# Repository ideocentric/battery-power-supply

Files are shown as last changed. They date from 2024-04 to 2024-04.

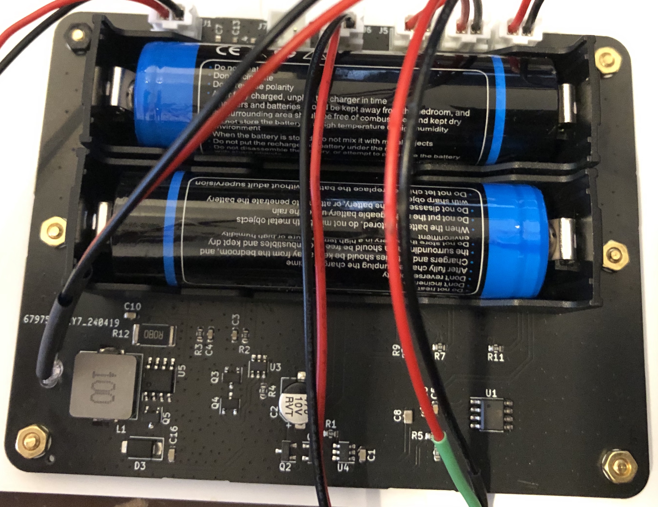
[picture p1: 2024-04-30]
battery-charger-supply.jpg

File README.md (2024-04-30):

# battery-power-supply
The purpose of this project is to have a rechargeable battery intended to be inside an enclosure for various synthesizer designs, however, it can be utilized for any purpose.

The motivation for this project was that I have not found an adequate solution.  There are a number of current solutions available, but the following limitations create issues for the overall design.

1.  Soldered on USB charging ports
2.  Soldered on power switch
3.  Soldered on power, charging and charge LEDs

Due to the above, they do not suite the usage inside of a project enclosure without desoldering these components and attaching wires in their place for panel mount switches, power and LEDs.

I have, however, found one solution that satisfied the above issues.  Unfortunately, these devices produced audible frequencies that prevented it being functional as a power supply for a sythesizer.

Due to the above conditions, I reached out to work with an engineer to help create the schematic and PCB layout for this purpose.  

The devise is intended to be used with 2 18650 batteries.  The JST connectors are provided to hook up the components such as the DC Barrel Jack for charging, 5v output for the device, Power switch and LEDs for Power, Charging and Charged status indicators.

The power supply should be 5v2a (or 5v3a).  Output is 5v1a.

I had the device manufactured at https://jlcpcb.com of which all components are normal stock items.

# Known Issues:
The current solution does not provide protection for low or short battery (perhaps this will be modified in a future version).

The status light output of the CN3302 IC is a little vague in it’s output as both lights appear to be on during charging.

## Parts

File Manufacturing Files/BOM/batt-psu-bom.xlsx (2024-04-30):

Comment | MFR | MFR-PN | Designator | Footprint | JLCPCB Part #（optional）
BH-18650-A5BJ001-2D | MYOUNG | BH-18650-A5BJ001-2D | BT1, BT2 | Battery:BatteryHolder_MPD_BH-18650-PC2 | C19184083
CL10A106MA8NRNC | Samsung Electro-Mechanics | CL10A106MA8NRNC | C1, C7, C10, C16 | Capacitor_SMD:C_0603_1608Metric | C96446
RVT1A471M0607 | Honor Elec | RVT1A471M0607 | C2 | Capacitor_SMD:CP_Elec_6.3x7.7 | C87858
0603B104K250CT | Walsin Tech Corp | 0603B104K250CT | C3, C4, C5, C13 | Capacitor_SMD:C_0603_1608Metric | C83054
0603X105M250NT | FH (Guangdong Fenghua Advanced Tech) | 0603X105M250NT | C6, C14 | Capacitor_SMD:C_0603_1608Metric | C2857985
CL21A226MAYNNNE | Samsung Electro-Mechanics | CL21A226MAYNNNE | C8 | Capacitor_SMD:C_0603_1608Metric | C602037
SS34 | JUXING | SS34 | D3 | Diode_SMD:D_SMA | C3011102
B2B-XH-A(LF)(SN) | JST | B2B-XH-A(LF)(SN) | J1, J2, J3, J5, J6, J7 | Connector_JST:JST_XH_B2B-XH-A_1x02_P2.50mm_Vertical | C158012
SLO1040H100MTT | Sunltech Tech | SLO1040H100MTT | L1 | Inductor_SMD:L_Wuerth_HCI-1040 | C182194
SI2347DS-T1-GE3 | Vishay Intertech | SI2347DS-T1-GE3 | Q1, Q2 | Package_TO_SOT_SMD:SOT-23 | C145002
FS3402 | FOSAN | FS3402 | Q3, Q4, Q5 | Package_TO_SOT_SMD:SOT-23 | C2926128
FRC0603J474 TS | FOJAN | FRC0603J474 TS | R1 | Resistor_SMD:R_0603_1608Metric | C2907171
FRC0603J331 TS | FOJAN | FRC0603J331 TS | R2, R3, R7, R9, R11 | Resistor_SMD:R_0603_1608Metric | C2907152
FRC0603J202 TS | FOJAN | FRC0603J202 TS | R4 | Resistor_SMD:R_0603_1608Metric | C2907137
FRC0603F6201TS | FOJAN | FRC0603F6201TS | R5 | Resistor_SMD:R_0603_1608Metric | C2907054
FRC0603J202 TS | FOJAN | FRC0603J202 TS | R6 | Resistor_SMD:R_0603_1608Metric | C2907137
25121WF800MT4E | UNI-ROYAL(Uniroyal Elec) | 25121WF800MT4E | R12 | Resistor_SMD:R_2512_6332Metric | C421509
MIC39102YM-TR | Microchip Tech | MIC39102YM-TR | U1 | Package_SO:SOIC-8_3.9x4.9mm_P1.27mm | C627993
HY2120-CB | HYCON Tech | HY2120-CB | U3 | Package_TO_SOT_SMD:SOT-23-6 | C116509
LTC4412ES6#TRPBF | Analog Devices | LTC4412ES6#TRPBF | U4 | Package_TO_SOT_SMD:TSOT-23-6 | C514442
CN3302 | ShangHai Consonance Elec | CN3302 | U5 | Package_SO:SOIC-8_3.9x4.9mm_P1.27mm | C559039

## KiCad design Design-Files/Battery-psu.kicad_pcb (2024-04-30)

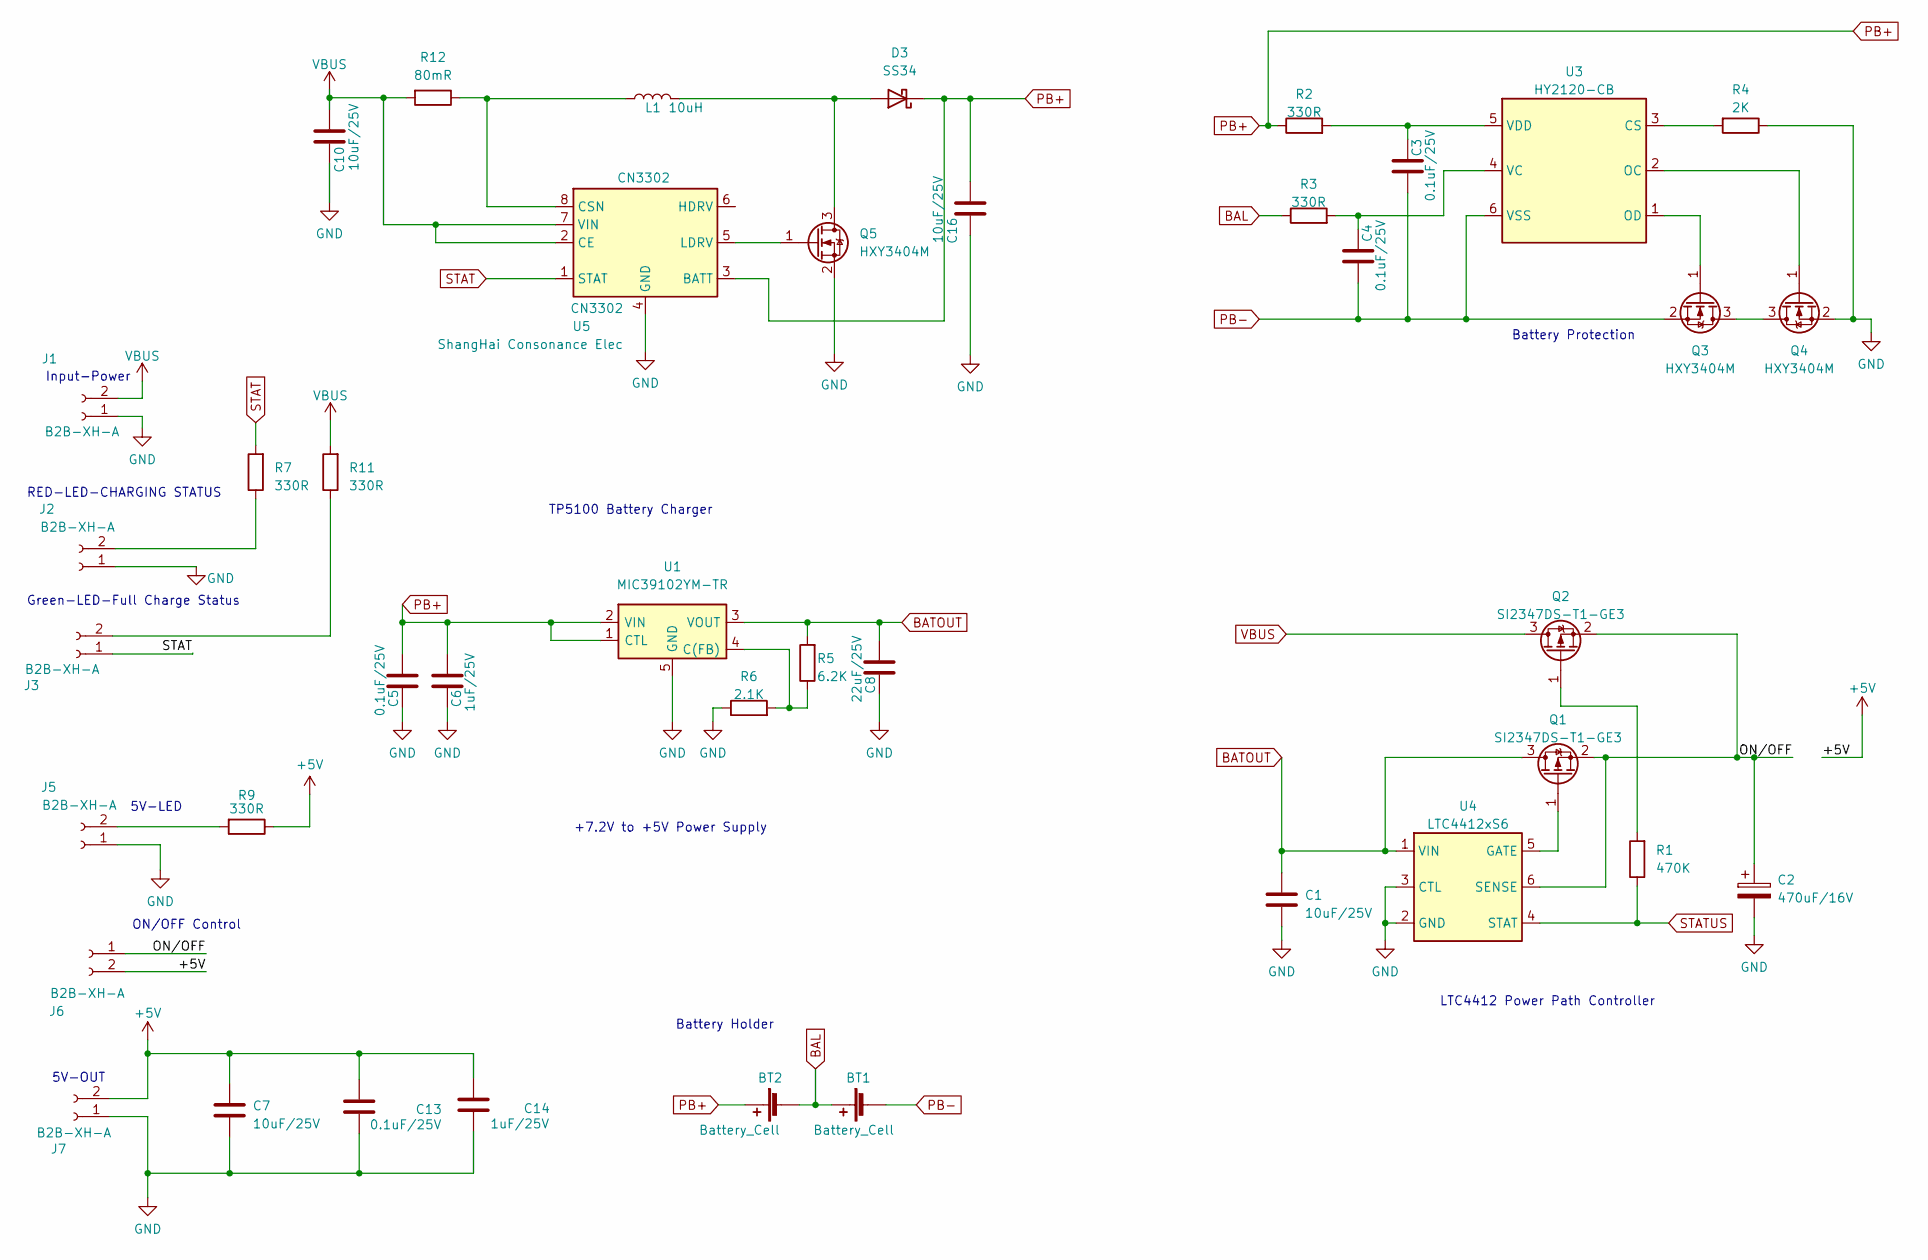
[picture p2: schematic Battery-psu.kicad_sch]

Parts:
BT1: Battery_Cell; BatteryHolder_MPD_BH-18650-PC2; LCSC-PN C19184083
BT2: Battery_Cell; BatteryHolder_MPD_BH-18650-PC2; LCSC PN C19184083
C1, C7, C10, C16: 10uF/25V; C_0603_1608Metric; LCSC PN C96446
C2: 470uF/16V; CP_Elec_6.3x7.7; LCSC PN C87858
C3, C4, C5, C13: 0.1uF/25V; C_0603_1608Metric; LCSC PN C83054
C6, C14: 1uF/25V; C_0603_1608Metric; LCSC PN C2857985
C8: 22uF/25V; C_0603_1608Metric; LCSC PN C602037
D3: SS34; D_SMA; LCSC PN C3011102
J1, J2, J3, J5, J6, J7: B2B-XH-A; JST_XH_B2B-XH-A_1x02_P2.50mm_Vertical; LCSC PN C158012
L1: 10uH; L_Wuerth_HCI-1040; LCSC PN C182194
Q1, Q2: SI2347DS-T1-GE3; SOT-23; LCSC PN C145002
Q3, Q4, Q5: HXY3404M; SOT-23; LCSC PN C2926128
R1: 470K; R_0603_1608Metric; LCSC PN C2907171
R2, R3, R7, R9, R11: 330R; R_0603_1608Metric; LCSC PN C2907152
R4: 2K; R_0603_1608Metric; LCSC PN C2907137
R5: 6.2K; R_0603_1608Metric; LCSC PN C2907054
R6: 2.1K; R_0603_1608Metric; LCSC PN C2907137
R12: 80mR; R_2512_6332Metric; LCSC PN C421509
U1: MIC39102YM-TR; SOIC-8_3.9x4.9mm_P1.27mm; LCSC PN C627993
U3: HY2120-CB; SOT-23-6; LCSC PN C116509
U4: LTC4412xS6; TSOT-23-6; LCSC PN C514442
U5: CN3302; SOIC-8_3.9x4.9mm_P1.27mm; LCSC PN C559039

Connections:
+5V: C7.1, C13.1, C14.1, J6.2, J7.2, R9.1
/ON/OFF: C2.1, J6.1, Q1.2 (S), Q2.2 (S), U4.6 (SENSE)
BAL: BT1.1 (+), BT2.2 (-), R3.1
BATOUT: C1.1, C8.1, Q1.3 (D), R5.2, U1.3 (VOUT), U4.1 (VIN)
GND: C1.2, C2.2, C5.2, C6.2, C7.2, C8.2, C10.2, C13.2, C14.2, C16.2, J1.1, J2.1, J5.1, J7.1, Q4.2 (S), Q5.2 (S), R4.1, R6.1, U1.5 (GND), U1.6 (GND), U1.7 (GND), U1.8 (GND), U4.2 (GND), U4.3 (CTL), U5.4 (GND)
unnamed: D3.2 (A), L1.2, Q5.3 (D)
unnamed: J2.2, R7.1
unnamed: J3.2, R11.1
unnamed: J5.2, R9.2
unnamed: Q1.1 (G), U4.5 (GATE)
unnamed: Q2.1 (G), R1.2
unnamed: Q3.3 (D), Q4.3 (D)
unnamed: Q3.1 (G), U3.1 (OD)
unnamed: Q4.1 (G), U3.2 (OC)
unnamed: Q5.1 (G), U5.5 (LDRV)
unnamed: R5.1, R6.2, U1.4 (C(FB))
unnamed: R4.2, U3.3 (CS)
unnamed: C4.1, R3.2, U3.4 (VC)
unnamed: C3.1, R2.2, U3.5 (VDD)
unnamed: L1.1, R12.1, U5.8 (CSN)
PB+: BT2.1 (+), C5.1, C6.1, C16.1, D3.1 (K), R2.1, U1.1 (CTL), U1.2 (VIN), U5.3 (BATT)
PB-: BT1.2 (-), C3.2, C4.2, Q3.2 (S), U3.6 (VSS)
STAT: J3.1, R7.2, U5.1 (STAT)
STATUS: R1.1, U4.4 (STAT)
VBUS: C10.1, J1.2, Q2.3 (D), R11.2, R12.2, U5.2 (CE), U5.7 (VIN)

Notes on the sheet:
ON/OFF Control
Battery Holder
5V-LED
+7.2V to +5V Power Supply
5V-OUT
LTC4412 Power Path Controller
RED-LED-CHARGING STATUS
Battery Protection
TP5100 Battery Charger
Green-LED-Full Charge Status
Input-Power

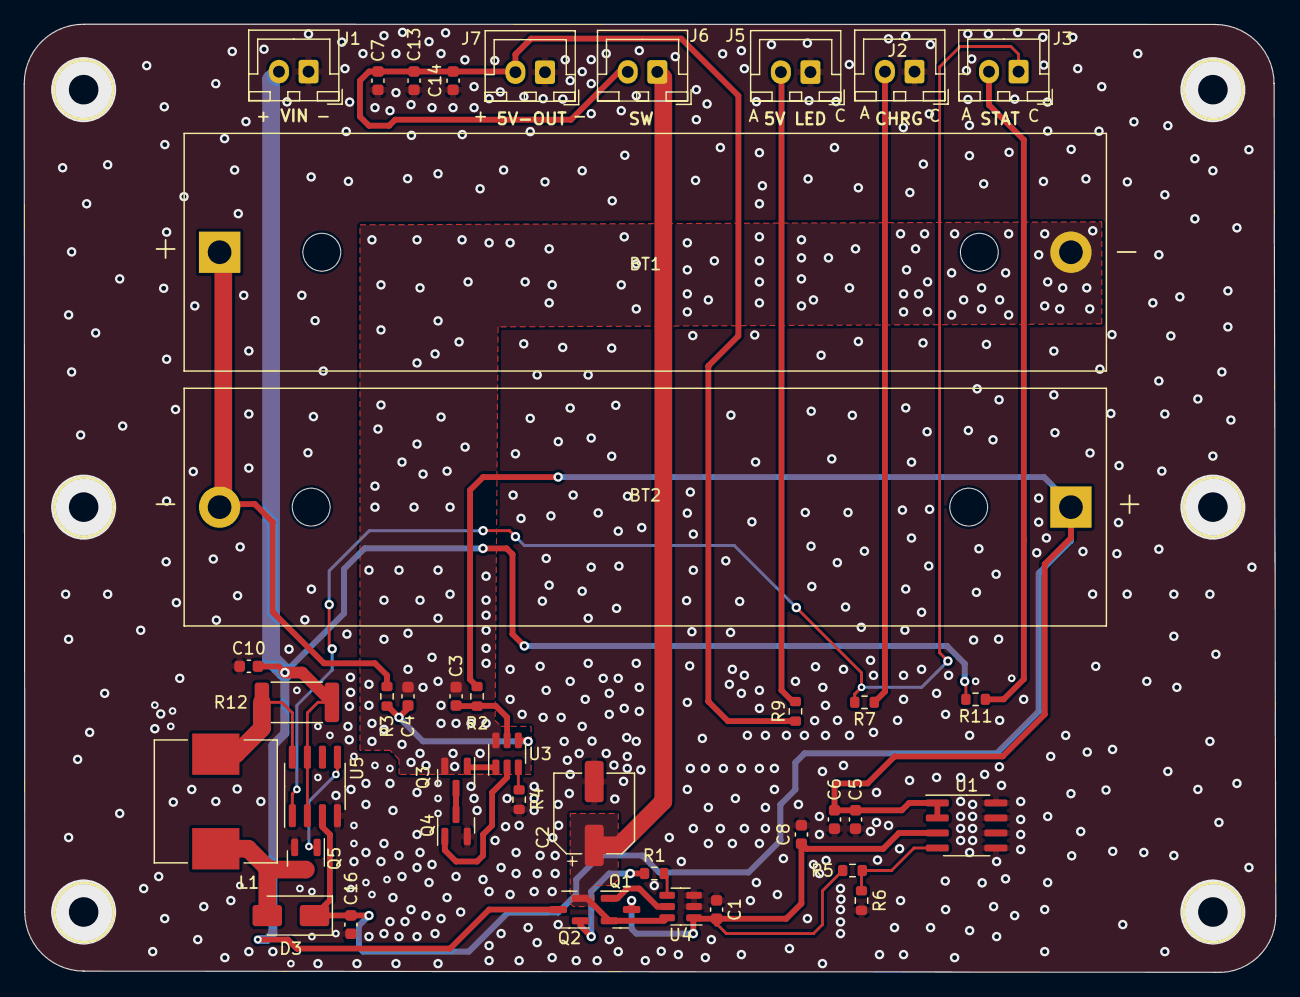
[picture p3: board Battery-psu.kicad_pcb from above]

Board: 2 copper layers, 105.8 x 80.2 mm, 41 parts (0 on the bottom side), 25 nets.
